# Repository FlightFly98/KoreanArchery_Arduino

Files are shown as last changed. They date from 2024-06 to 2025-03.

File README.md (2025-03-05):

# XRKoeanArchery_Arduino
Capstone Design - Kyung Hee University SWCON

## 국궁 실내 습사 프로젝트

이 아두이노 파일은 유니티와 같이 동작합니다.

참조: https://github.com/FlightFly98/VRKoreanArchery

## 준비물

### 1. 가속도 & 자이로 손목 트래커 2개

 > **센서**
 - Wemos D1 mini 2개
 - mpu6050 (가속도 & 자이로 센서) 2개
 - TP4056 (c-type 충전 포트) 2개
 - 리튬 배터리 523450 2개

 - 회로도<br>
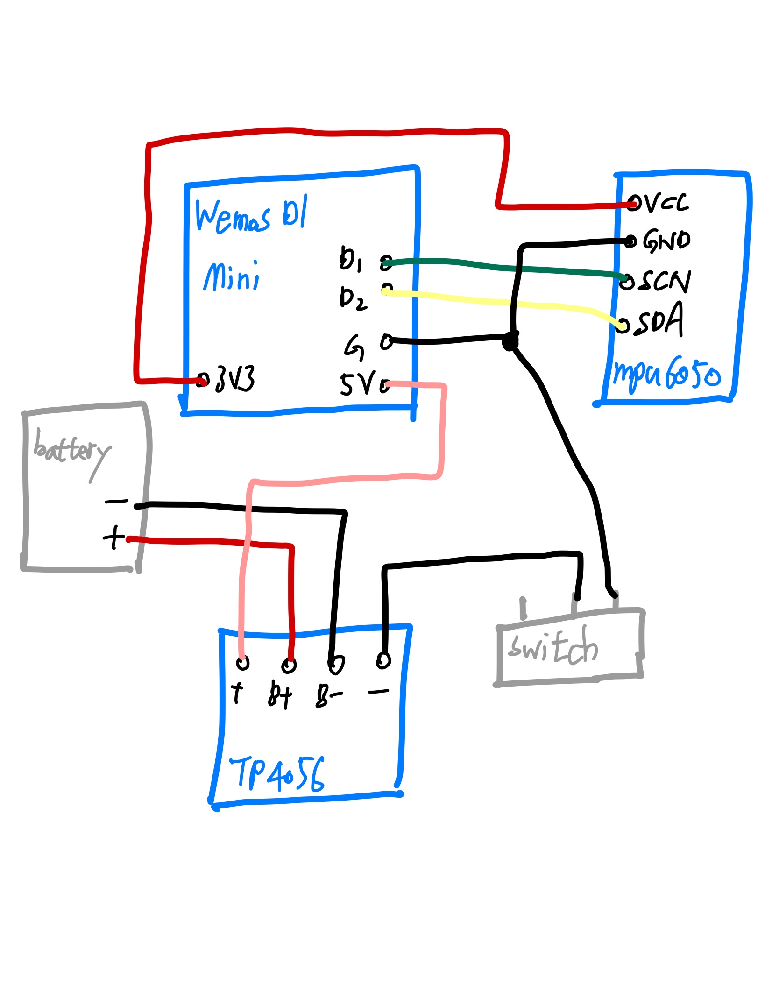
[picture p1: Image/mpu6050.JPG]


***

### 2. 충격 감지 센서 1개

 > **센서**
 - Wemos D1 mini 1개
 - Sw420 (충격 감지 센서) 1개
 - TP4056 (c-type 충전 포트) 1개
 - 리튬 배터리 523450 1개 
 - 회로도 <br>
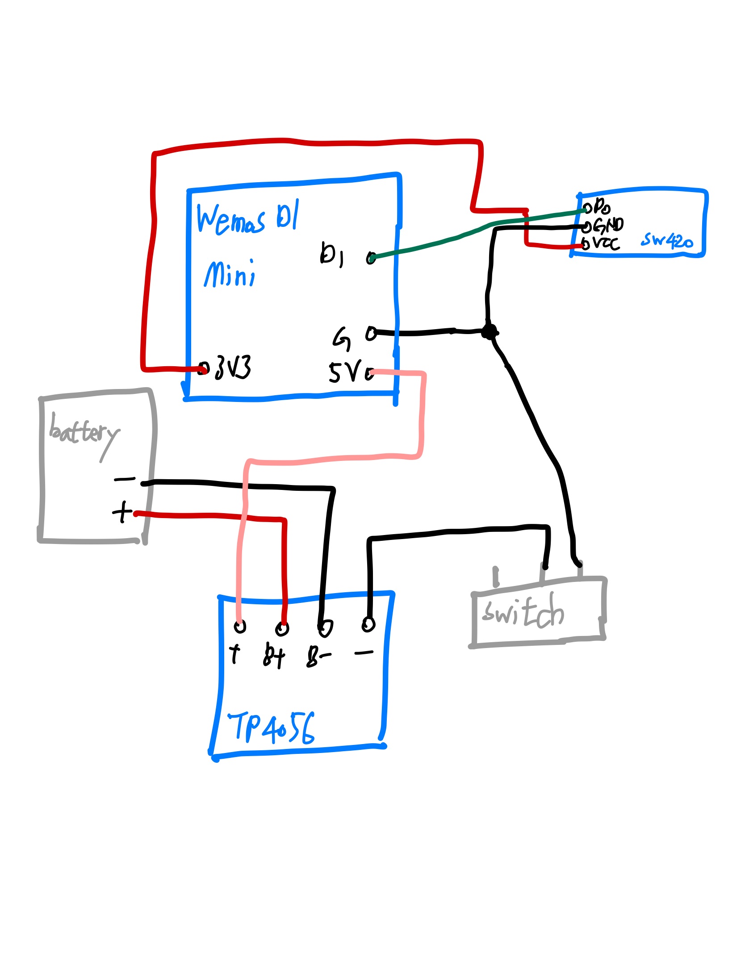
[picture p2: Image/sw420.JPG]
 

***

### 3. 낙전 감지 센서 1개 (필수 아님!)
 > **센서**
 - Wemos D1 mini 1개
 - 적외선 트레이서 1개

실제 구동 시 전원만 연결 되어 있으면 됩니다!

## 구동 방법

### 1) 기본 납땜 및 업로드

1. 위 센서들을 전부 납땜합니다.

2. 가속도 & 자이로 센서 1개엔 mpu6050_ZoomHand, 다른 1개엔 mpu6050_KkagjHand를 업로드합니다.

3. 충격 감지 센서에 sw420_EX를 업로드합니다.

4. 낙전 감지 센서에 Nakjeon을 업로드합니다.

5. 케이스: Case 폴더에 3D프린트 도면 있습니다!<br>

- Mpu6050 body,Cover,Pane 각 2개씩

- Sw420 1개

- 전체 도면 사진

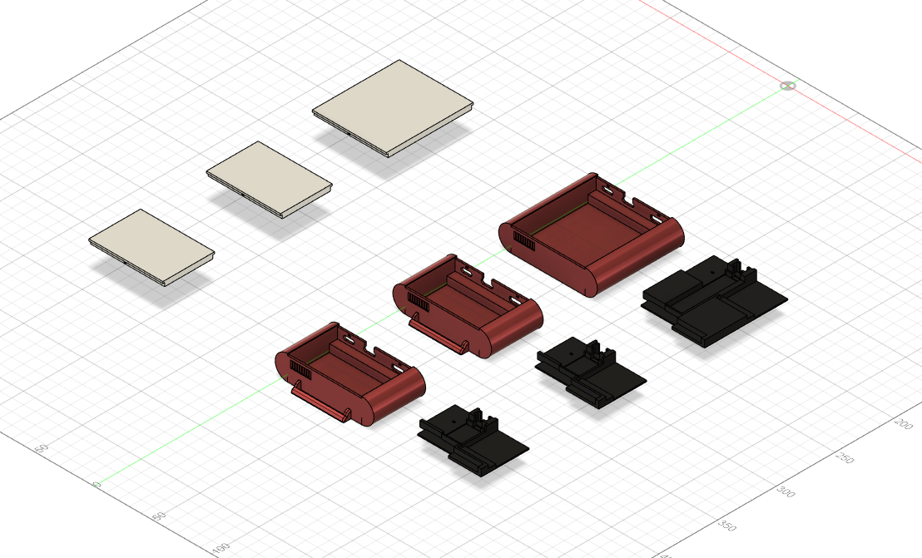
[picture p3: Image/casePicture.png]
 

### 2) 와이파이 설정 - 아두이노

#### 1. mpu6050_ZoomHand의 전원을 킵니다. <br>
>> const char* ssid = "WemosD1_ZoomHand" => 와이파이 이름<br>
  const char* password = "love00007" => 와이파이 비밀번호<br>

- mpu6050_ZoomHand는 WiFi Ap 역할을 합니다.
- 모든 아두이노가 현재 ap의 이름과 비밀번호로 접속 할 수 있습니다.
- 수정 가능하지만, 모든 아두이노의 접속하려는 ssid와 passward를 수정하여야 합니다.
- 먼저 mpu6050_ZoomHand 전원을 켜야 통신할 와이파이가 생깁니다.

#### 2. 컴퓨터를 mpu6050_ZoomHand의 와이파이에 연결합니다.
- 이 와이파이는 인터넷이 없는 와이파이입니다.
- 어떤 pc는 인터넷이 없는 와이파이는 자동으로 연결 해제하므로 **네트워크 초기화**가 필요할 수 있습니다.

#### 3. 방화벽의 인바운드 규칙을 설정합니다.
- UDP 통신을 위한 포트를 열어줍니다.
- 방화벽 -> 고급 설정 -> 인바운드 규칙 -> 새 규칙
- UDP 및 12346 ~ 12350의 포트를 제한없이 열어둡니다.
- 만약 이 규칙을 적용해도 유니티에서 적용이 안 될 경우, 방화벽을 임시로 해제하고 실행해야 합니다.

#### 4. 다른 모든 아두이노 전원도 킵니다.

#### 5. Server 폴더에서 터미널을 열고 python server.py로 서버를 작동합니다.

 ```python
def get_ip_address():
    result = subprocess.run(["powershell.exe", "-ExecutionPolicy", "Bypass", "-File", "..\\Server\\GetIP.ps1"], capture_output=True, text=True)
    ip_address = result.stdout.strip()
    return ip_address
 ```
 - "..\\Server\\GetIP.ps1" 이 자리에 본인의 GetIP.ps1가 위치한 파일 경로를 넣으셔야 합니다.
 - 모든 아두이노가 연결이 되었는지 확인합니다.
 - "Device at {ip}:{port} is still connected." 또는 "Device at {ip}:{port} reconnected." 메세지가 뜬다면 연결 성공입니다.

#### 6. 모두 연결이 되었다면 아두이노는 준비 완료!

#### 7. 가속도 & 자이로 센서를 손목에 착용합니다.

 다시 돌아가기: https://github.com/FlightFly98/VRKoreanArchery

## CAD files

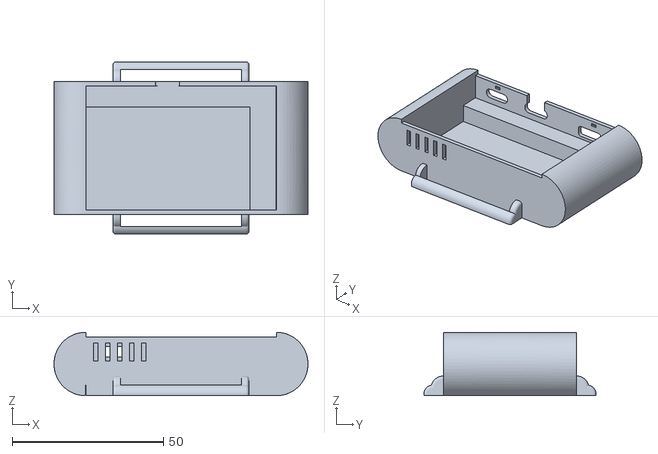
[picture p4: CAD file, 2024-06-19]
Case/Mpu6050_Body.stl
84.0 x 57.0 x 21.0

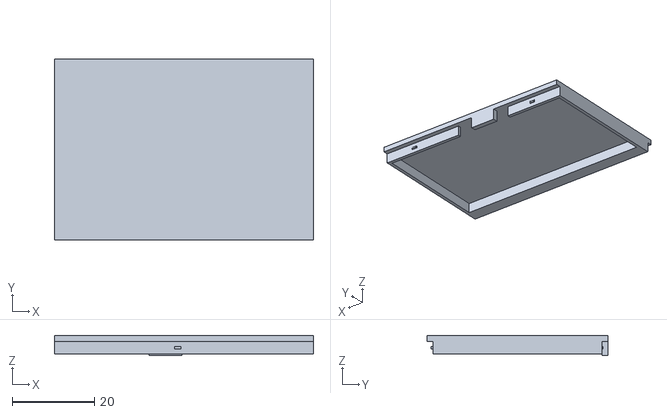
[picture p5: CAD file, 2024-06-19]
Case/Mpu6050_Cover.stl
63.0 x 44.0 x 4.88

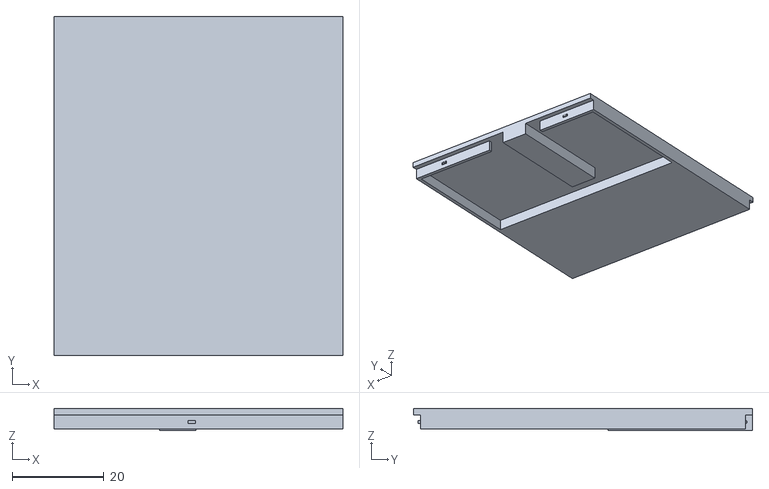
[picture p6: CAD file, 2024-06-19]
Case/Sw420_Cover.stl
63.0 x 74.0 x 4.88

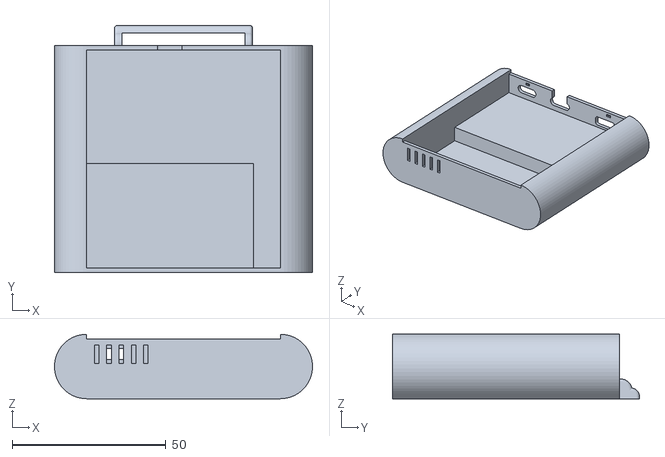
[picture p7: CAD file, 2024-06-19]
Case/Sw420_Body.stl
84.0 x 80.5 x 21.0

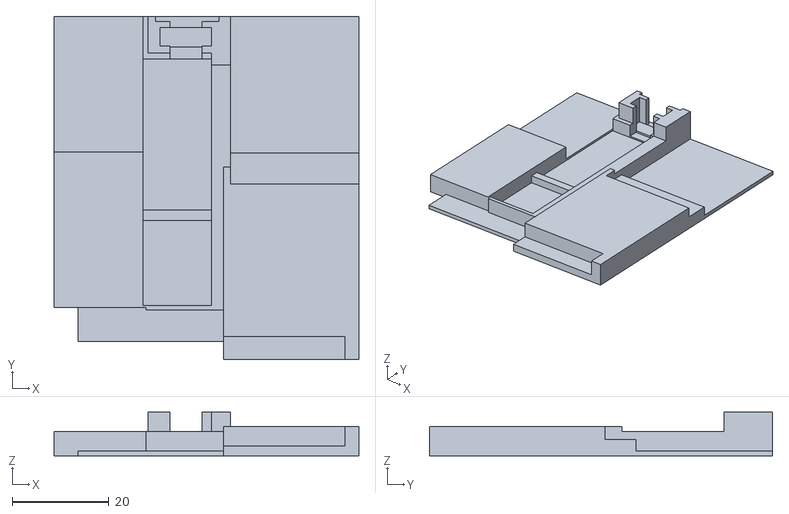
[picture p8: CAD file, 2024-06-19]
Case/Sw420_Pane.stl
62.9 x 70.8 x 9.00

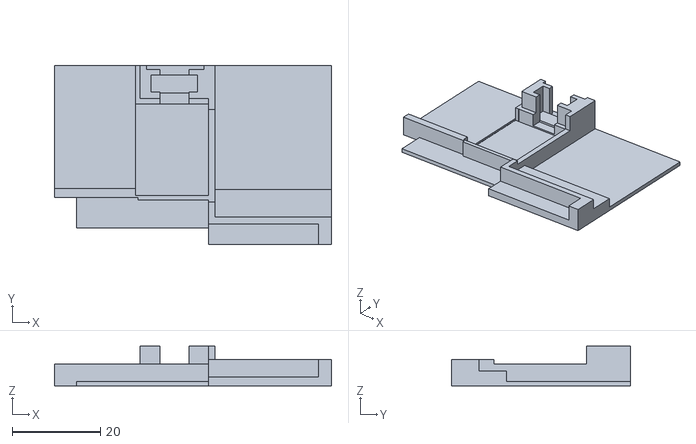
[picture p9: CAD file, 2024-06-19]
Case/Mpu6050_Pane.stl
62.9 x 40.8 x 9.00

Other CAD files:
Case/Mpu6050_Body.f3d
Case/Mpu6050_Cover.f3d
Case/Mpu6050_Pane.f3d
Case/Sw420_Body.f3d
Case/Sw420_Cover.f3d
Case/Sw420_Pane.f3d

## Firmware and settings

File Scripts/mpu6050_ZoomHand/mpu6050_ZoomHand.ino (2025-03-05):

#include <ESP8266WiFi.h>
#include <WiFiUdp.h>
#include <Wire.h>
#include "DFRobot_BMI160.h"
#include <Adafruit_HMC5883_U.h>

const char* ssid = "Gukgung_Wifi";
const char* password = "love00007";
IPAddress local_IP(192, 168, 4, 2);
IPAddress gateway(192, 168, 4, 1);
IPAddress subnet(255, 255, 255, 0);

WiFiUDP Udp;
IPAddress udpAddress; // 유니티가 실행되는 PC의 IP 주소
const int udpPort = 12346;

bool ipAcquired = false;

DFRobot_BMI160 bmi160;
Adafruit_HMC5883_Unified mag = Adafruit_HMC5883_Unified(67890);

void setup() {
  Serial.begin(115200);

  setWiFiAp();
  
  Wire.begin(D2, D1);
  
  initBmiHMC();
  
  Udp.begin(udpPort);

}

void loop() {
  if (!ipAcquired) {
    waitForPCIP();
  } else {
    sendSensorData();
    waitForCheckMessage();
  }
}

void setWiFiAp()
{
  WiFi.softAPConfig(local_IP, gateway, subnet);
  WiFi.softAP(ssid, password);
  delay(10000); // AP 설정을 위한 시간 대기
  Serial.println("AP mode set");
}

void setWiFiConnect()
{
  WiFi.begin(ssid, password);
  WiFi.config(local_IP, gateway, subnet);

  while (WiFi.status() != WL_CONNECTED) {
    delay(2000);
    Serial.println("Connecting to WiFi...");
  }

  Serial.println("Connected to WiFi");
}

void initBmiHMC() {
  int8_t initStatus = bmi160.I2cInit(0x69);
    if (initStatus != BMI160_OK) {
        Serial.print("BMI160 initialization failed! Error code: ");
        Serial.println(initStatus);
        while (1);
    }

    Serial.println("BMI160 initialized successfully!");

    delay(100);
    
    int16_t dummyData[3];
    if (bmi160.getAccelData(dummyData) != BMI160_OK || bmi160.getGyroData(dummyData) != BMI160_OK) {
        Serial.println("Sensor is not responding! Retrying...");
        delay(500);
        bmi160.I2cInit(0x69);
    }

    Serial.println("Reading accelerometer and gyroscope data...");

     if (!mag.begin()) {
        Serial.println("HMC5883L not detected! Check wiring.");
        while (1);
    }

    Serial.println("HMC5883L initialized successfully!");

    Serial.println("Reading sensor data...");
}


void waitForPCIP() {
  int packetSize = Udp.parsePacket();
  if (packetSize) 
  {
    char packetBuffer[255];
    int len = Udp.read(packetBuffer, 255);
    if (len > 0) 
    {
      packetBuffer[len] = 0;
      Serial.println(packetBuffer);

      // PC IP 주소를 수신한 경우 ACK 응답 전송
      if (strcmp(packetBuffer, "Hello from PC") == 0) 
      { // 확인 메시지 추가
        Udp.beginPacket(Udp.remoteIP(), Udp.remotePort());
        Udp.write("ACK");
        Udp.endPacket();
        Serial.println("Sent ACK");

        udpAddress = Udp.remoteIP();
        Serial.print("Received packet from IP: ");
        Serial.println(udpAddress);
        ipAcquired = true;
        Serial.println("Set udpAddress");
      } 
    }
  }
}



void waitForCheckMessage() 
{
  int packetSize = Udp.parsePacket();
  if (packetSize) 
  {
    char packetBuffer[255];
    int len = Udp.read(packetBuffer, 255);
    if (len > 0) 
    {
      packetBuffer[len] = 0;
      Serial.println(packetBuffer);
      if(strcmp(packetBuffer, "Check connection") == 0)
      {
        Udp.beginPacket(Udp.remoteIP(), Udp.remotePort());
        Udp.write("ACK");
        Udp.endPacket();
        Serial.println("Sent ACK");
      }
    }
  }
}


void sendSensorData() {
  int16_t acc_raw[3];
  int16_t gyro_raw[3];

  if (bmi160.getAccelData(acc_raw) != BMI160_OK) {
        Serial.println("Failed to read accelerometer data!");
    }
  if (bmi160.getGyroData(gyro_raw) != BMI160_OK) {
        Serial.println("Failed to read gyroscope data!");
    }

   // HMC5883L 데이터 읽기
   sensors_event_t event;
   mag.getEvent(&event);

   // 방위각(Yaw) 계산
   // float heading = atan2(event.magnetic.y, event.magnetic.x);
   // if (heading < 0) heading += 2 * PI;
   // float headingDegrees = heading * 180 / PI;

  char str[256];
  snprintf(str, sizeof(str), "Accel: %d, %d, %d, Gyro: %d, %d, %d, Mag: %d, %d",
  acc_raw[0], acc_raw[1], acc_raw[2],
  gyro_raw[0], gyro_raw[1], gyro_raw[2],
  (int16_t) event.magnetic.x, (int16_t) event.magnetic.y);
  
  Serial.println(str);

  Udp.beginPacket(udpAddress, udpPort);
  Udp.write(str);
  Udp.endPacket();

  delay(100);
}

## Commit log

2024-06-19 최종 수정
2024-06-19 gitignore 추가
2024-06-19 Readme 추가
2024-06-19 readme 수정
2024-06-19 server.py 수정
2024-10-07 server, AP 수정
